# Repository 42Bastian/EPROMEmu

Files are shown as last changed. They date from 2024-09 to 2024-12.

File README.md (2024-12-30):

# LynxCartEmu

This repo is based on Brian's repo, see original comments below.

This fork is solely to support Atari Lynx Carts.
Upon start, the firmware loads either a `game.lnx` file or if not available provides a uBLL for Lynx.

A new ROM image can be uploaded (as .lnx file) and will be stored in internal RAM and on SD card (if available) for the next boot.

Sending is done via `SendCard.py`.

The firmware allows to "reload" the SD cart via serial command `cr` if game.lnx was saved on a PC on the card.

---

# EPROMEmu

**!! WARNING: I have no idea what I'm doing !!**

I've decided to make this public in the rare event it might help someone.

This is a very simple, likely very wrong (EP)ROM emulator using a Teensy 4.1 and Arduino/PlatformIO.  It works for my purposes (emulating an EPROM for
use in an Atari Lynx EPROM cartridge), but it it is probably not the "correct" way to design hardware.  I have also used it on Game Gear and Vectrex EPROM cartridges,
but it was not heavily tested.

Please take caution with using anything you see here.  It's my first time using KiCad, my first time designing a PCB, and my first time creating hardware.  Again,
it works for my purposes, but perhaps it'll burn your house down.

Enjoy!

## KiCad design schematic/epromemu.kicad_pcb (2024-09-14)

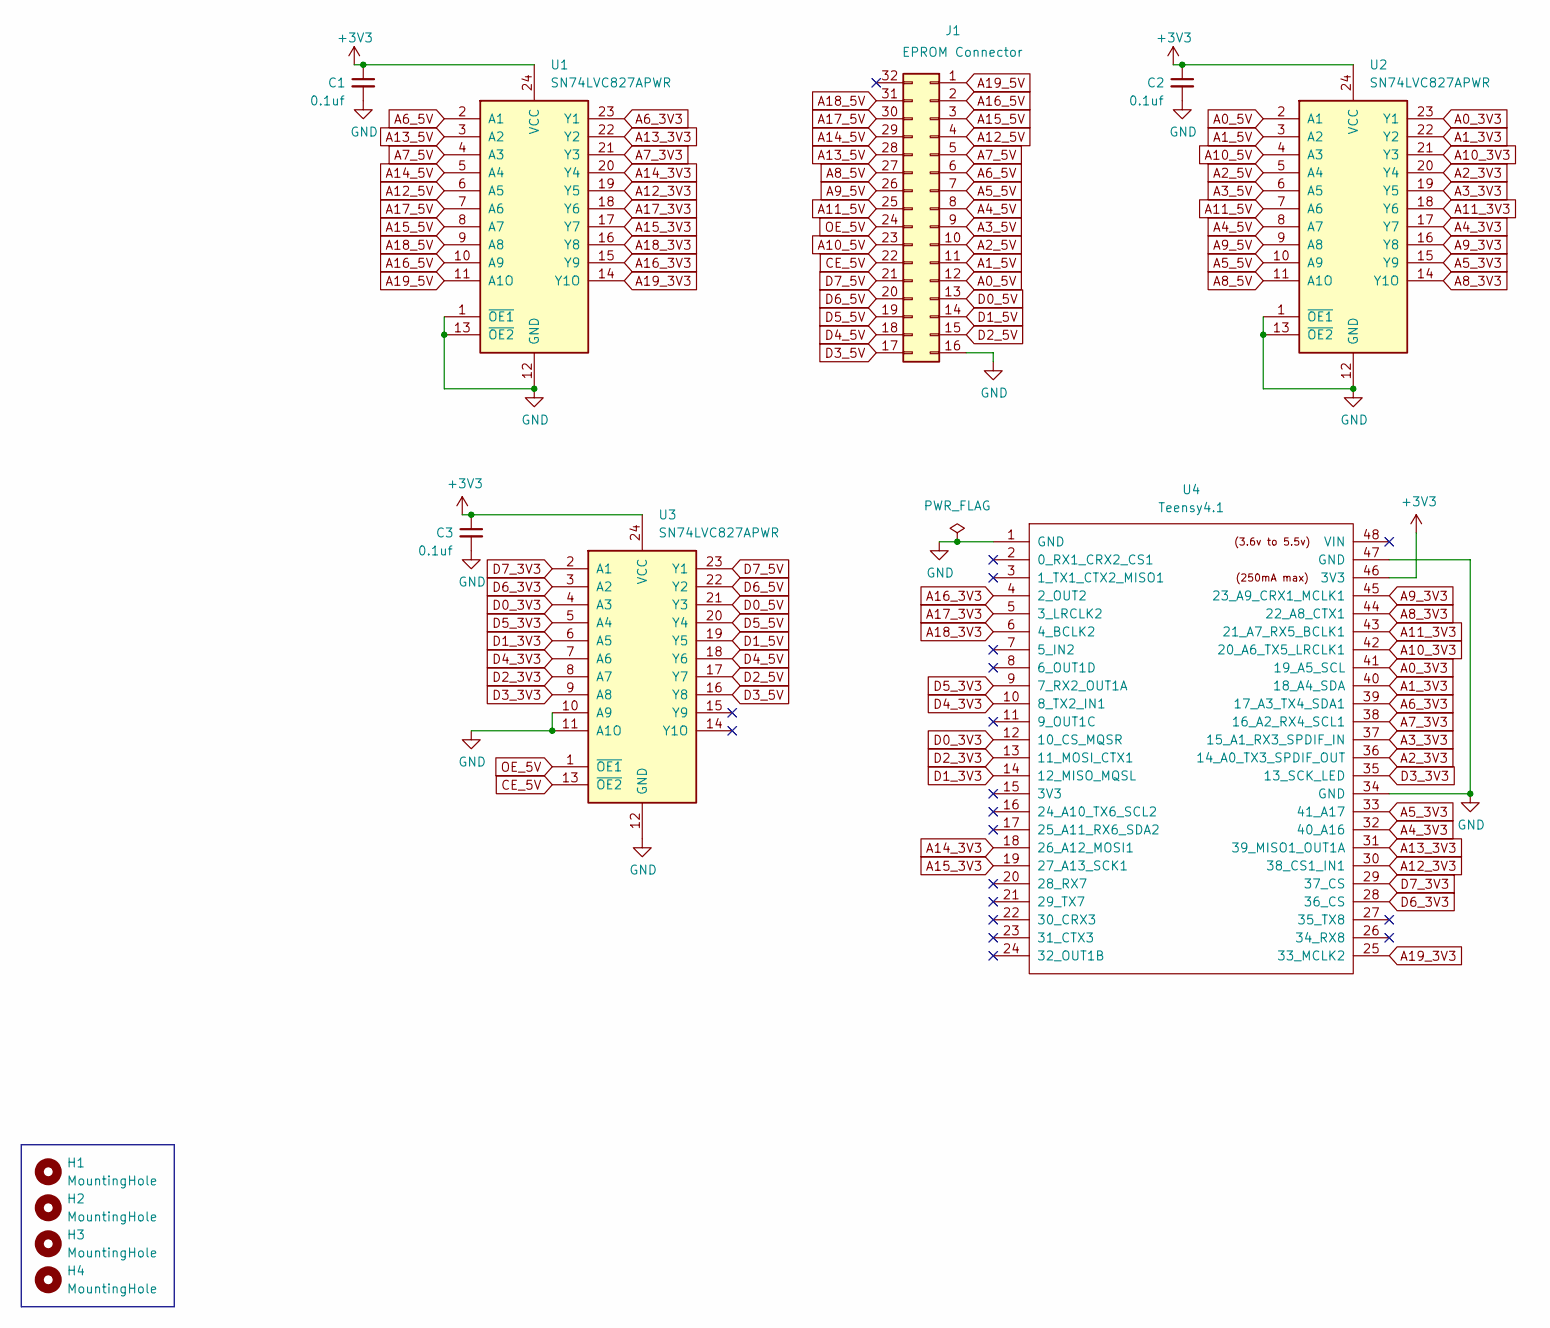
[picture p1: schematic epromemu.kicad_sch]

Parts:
C1, C2, C3: 0.1uf; C_0603_1608Metric_Pad1.08x0.95mm_HandSolder
H1, H2, H3, H4: MountingHole; MountingHole_2.2mm_M2_ISO7380
J1: EPROM Connector; PinHeader_2x16_P2.54mm_Vertical
U1, U2, U3: SN74LVC827APWR; SOIC-24W_7.5x15.4mm_P1.27mm
U4: Teensy4.1; Teensy41

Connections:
+3V3: C1.1, C2.1, C3.1, U1.24 (VCC), U2.24 (VCC), U3.24 (VCC), U4.46 (3V3)
A0_3V3: U2.23 (Y1), U4.41 (19_A5_SCL)
A0_5V: J1.12, U2.2 (A1)
A1_3V3: U2.22 (Y2), U4.40 (18_A4_SDA)
A1_5V: J1.11, U2.3 (A2)
A2_3V3: U2.20 (Y4), U4.36 (14_A0_TX3_SPDIF_OUT)
A2_5V: J1.10, U2.5 (A4)
A3_3V3: U2.19 (Y5), U4.37 (15_A1_RX3_SPDIF_IN)
A3_5V: J1.9, U2.6 (A5)
A4_3V3: U2.17 (Y7), U4.32 (40_A16)
A4_5V: J1.8, U2.8 (A7)
A5_3V3: U2.15 (Y9), U4.33 (41_A17)
A5_5V: J1.7, U2.10 (A9)
A6_3V3: U1.23 (Y1), U4.39 (17_A3_TX4_SDA1)
A6_5V: J1.6, U1.2 (A1)
A7_3V3: U1.21 (Y3), U4.38 (16_A2_RX4_SCL1)
A7_5V: J1.5, U1.4 (A3)
A8_3V3: U2.14 (Y1O), U4.44 (22_A8_CTX1)
A8_5V: J1.27, U2.11 (A1O)
A9_3V3: U2.16 (Y8), U4.45 (23_A9_CRX1_MCLK1)
A9_5V: J1.26, U2.9 (A8)
A10_3V3: U2.21 (Y3), U4.42 (20_A6_TX5_LRCLK1)
A10_5V: J1.23, U2.4 (A3)
A11_3V3: U2.18 (Y6), U4.43 (21_A7_RX5_BCLK1)
A11_5V: J1.25, U2.7 (A6)
A12_3V3: U1.19 (Y5), U4.30 (38_CS1_IN1)
A12_5V: J1.4, U1.6 (A5)
A13_3V3: U1.22 (Y2), U4.31 (39_MISO1_OUT1A)
A13_5V: J1.28, U1.3 (A2)
A14_3V3: U1.20 (Y4), U4.18 (26_A12_MOSI1)
A14_5V: J1.29, U1.5 (A4)
A15_3V3: U1.17 (Y7), U4.19 (27_A13_SCK1)
A15_5V: J1.3, U1.8 (A7)
A16_3V3: U1.15 (Y9), U4.4 (2_OUT2)
A16_5V: J1.2, U1.10 (A9)
A17_3V3: U1.18 (Y6), U4.5 (3_LRCLK2)
A17_5V: J1.30, U1.7 (A6)
A18_3V3: U1.16 (Y8), U4.6 (4_BCLK2)
A18_5V: J1.31, U1.9 (A8)
A19_3V3: U1.14 (Y1O), U4.25 (33_MCLK2)
A19_5V: J1.1, U1.11 (A1O)
CE_5V: J1.22, U3.13 (~OE2)
D0_3V3: U3.4 (A3), U4.12 (10_CS_MQSR)
D0_5V: J1.13, U3.21 (Y3)
D1_3V3: U3.6 (A5), U4.14 (12_MISO_MQSL)
D1_5V: J1.14, U3.19 (Y5)
D2_3V3: U3.8 (A7), U4.13 (11_MOSI_CTX1)
D2_5V: J1.15, U3.17 (Y7)
D3_3V3: U3.9 (A8), U4.35 (13_SCK_LED)
D3_5V: J1.17, U3.16 (Y8)
D4_3V3: U3.7 (A6), U4.10 (8_TX2_IN1)
D4_5V: J1.18, U3.18 (Y6)
D5_3V3: U3.5 (A4), U4.9 (7_RX2_OUT1A)
D5_5V: J1.19, U3.20 (Y4)
D6_3V3: U3.3 (A2), U4.28 (36_CS)
D6_5V: J1.20, U3.22 (Y2)
D7_3V3: U3.2 (A1), U4.29 (37_CS)
D7_5V: J1.21, U3.23 (Y1)
GND: C1.2, C2.2, C3.2, J1.16, U1.1 (~OE1), U1.12 (GND), U1.13 (~OE2), U2.1 (~OE1), U2.12 (GND), U2.13 (~OE2), U3.10 (A9), U3.11 (A1O), U3.12 (GND), U4.1 (GND), U4.34 (GND), U4.47 (GND)
OE_5V: J1.24, U3.1 (~OE1)

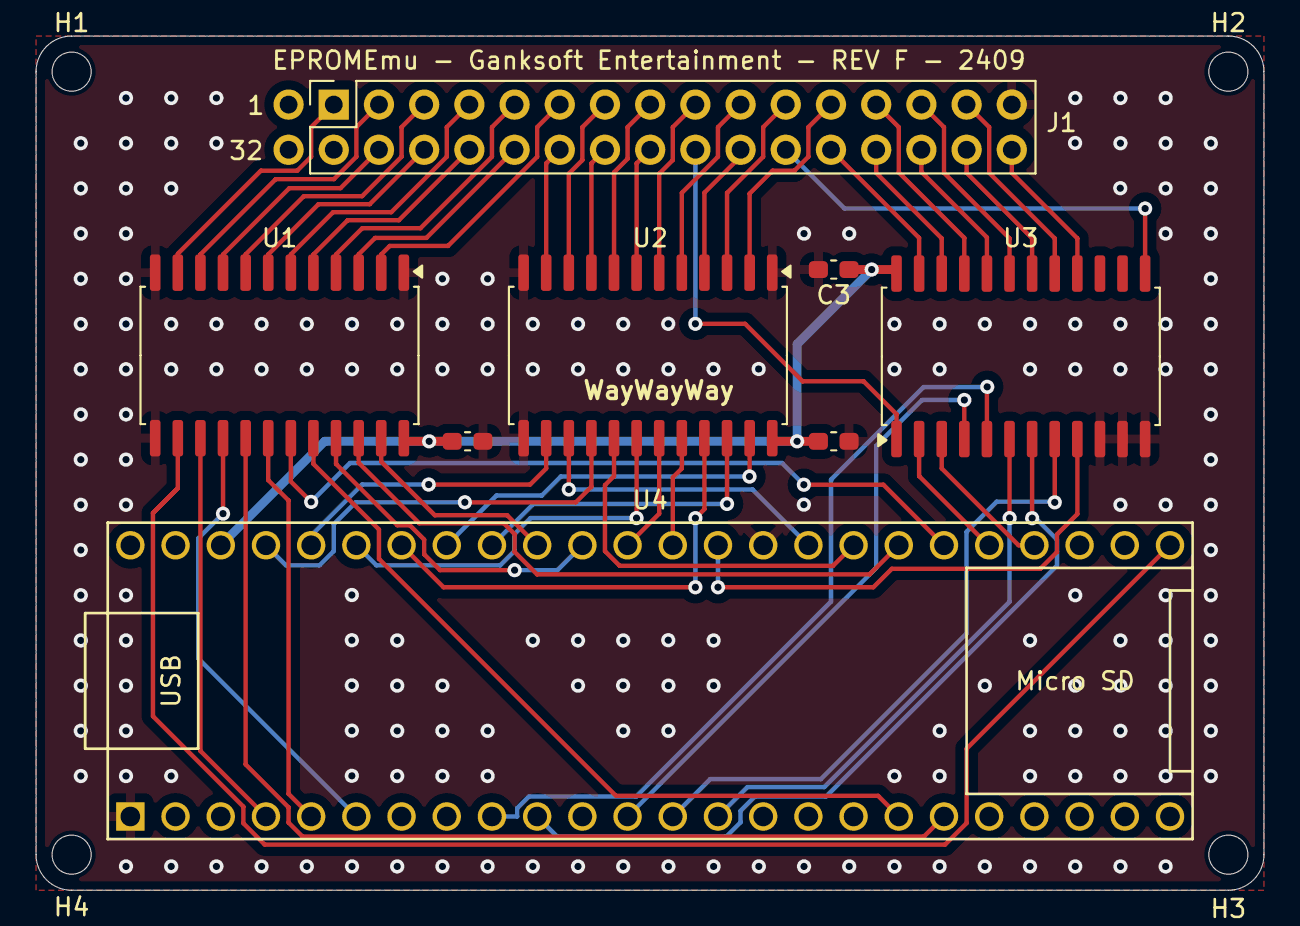
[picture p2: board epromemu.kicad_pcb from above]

Board: 2 copper layers, 69.0 x 48.0 mm, 13 parts (1 on the bottom side), 60 nets.

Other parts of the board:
GanksoftLogo: LOGO; GanksoftLogo

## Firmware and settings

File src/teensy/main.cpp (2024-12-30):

/*
** Teensy 4.1 firmware for LynxCartEmu
**
** (c) 2024 Brian Peek (original) and 42Bastian Schick (Lynx version)
**
*/
// FLASHMEM
// DMAMEM
// PROGMEM

#include <Arduino.h>
#include <SD.h>
#include <stdint.h>
#include "ubll.h"

enum cardSize : uint8_t {
  _128K = 1,
  _256K = 2,
  _512K = 3,
  _1M = 4,
};

typedef struct
{
  uint8_t  magic[4];
  uint16_t page_size_bank0;
  uint16_t page_size_bank1;
  uint16_t version;
  char     cartname[32];
  char     manufname[16];
  char     rotation;
  char     audBit;
  char     eeprom;
  char     spare[3];
} lnx_header_t;

constexpr size_t   ROM_BUFFER_LEN       = (256*1024);
constexpr uint32_t ROM_BUFFER_HI_MASK   = (ROM_BUFFER_LEN-1);
constexpr size_t   TOTAL_ROM_BUFFER_LEN = (2*ROM_BUFFER_LEN);

uint8_t bufferLo[ROM_BUFFER_LEN] {};
DMAMEM uint8_t bufferHi[ROM_BUFFER_LEN] {};

const int32_t inPins[]  = {
  19,18,14,15,40,41,17,16,22,23,20,21,38,39,26,27,2,3,4,33, -1
};
const int32_t outPins[] = {
  10,12,11,13,8,7,36,37, -1
};

constexpr const char *filenameLNX      = "game.lnx";
FS* g_fs = nullptr;
lnx_header_t lnx_header;
cardSize cSize = _256K;

int readLNX(Stream *s)
{
  size_t read;
  size_t total;
  uint8_t *buffer;
  size_t expected;

  memset(bufferLo, 0x42, sizeof(bufferLo));
  memset(bufferHi, 0x42, sizeof(bufferHi));
  memset(&lnx_header, 0xea, sizeof(lnx_header_t));

  read = s->readBytes((uint8_t *)&lnx_header, sizeof(lnx_header_t));

  expected = lnx_header.page_size_bank0 * 256;
  expected += lnx_header.page_size_bank1 * 256;

  total = 0;
  buffer = bufferLo;
  while( total < sizeof(bufferLo) && expected > 0 ){
    size_t wanted;

    wanted = sizeof(bufferLo) - total;
    wanted = wanted > 1024 ? 1024 : wanted;
    read = s->readBytes(buffer, wanted);
    if ( read <= 0 ) return 0;
    total += read;
    buffer += read;
    expected -= read;
  }
  total -= sizeof(bufferLo);

  buffer = bufferHi;
  while( total < sizeof(bufferHi) && expected > 0 ){
    size_t wanted;

    wanted = sizeof(bufferHi) - total;
    wanted = wanted > 1024 ? 1024 : wanted;
    read = s->readBytes(buffer, wanted);
    if ( read <= 0 ) return 0;
    total += read;
    buffer += read;
    expected -= read;
  }

  if( expected != 0 ) {
    return 0;
  }

  switch (lnx_header.page_size_bank0){
  case 512:
    cSize = _128K;
    break;
  case 1024:
    cSize = _256K;
    break;
  case 2048:
    cSize = _512K;
    break;
  default:
    cSize = _1M;
  }

  if ( g_fs->exists(filenameLNX)) {
    g_fs->remove(filenameLNX);
  }

  File f = g_fs->open(filenameLNX, FILE_WRITE);

  if ( f ){
    f.write((uint8_t *)&lnx_header, sizeof(lnx_header_t));

    expected = lnx_header.page_size_bank0 * 256;
    expected += lnx_header.page_size_bank1 * 256;

    f.write(bufferLo, min(sizeof(bufferLo),expected));
    f.write(bufferHi, expected-sizeof(bufferLo));
    f.close();
  }
  return 1;
}

void setPinMode(const int32_t* pins, uint32_t direction)
{
  for(int i = 0; pins[i] != -1; i++){
    pinMode(pins[i], direction);
  }
}

void checkSD()
{
  SD.begin(BUILTIN_SDCARD);
  g_fs = (FS*)&SD;

  if ( g_fs->exists(filenameLNX)) {
    Serial.printf("=> Found game.lnx:");

    File f = g_fs->open(filenameLNX, FILE_READ);
    int32_t sz = (int32_t)f.size();

    f.read(&lnx_header,64);
    Serial.printf("Size %ld\r\n",sz);
    Serial.flush();
    sz -= 64;
    f.read(bufferLo, min(sz,(int32_t)sizeof(bufferLo)));
    sz -= sizeof(bufferLo);
    if ( sz > 0 ){
      f.read(bufferHi,sz);
    }
    switch (lnx_header.page_size_bank0){
    case 512:
      cSize = _128K;
      break;
    case 1024:
      cSize = _256K;
      break;
    case 2048:
      cSize = _512K;
      break;
    default:
      cSize = _1M;
    }
    Serial.printf("Banksize: %d\r\n%s\r\n",cSize,lnx_header.cartname);
    f.close();
  } else {
    Serial.printf("No file found, switch to uBLL\r\n");
    memcpy(bufferLo, uBLL, sizeof(uBLL));
    strcpy(lnx_header.cartname, "uBLL");
    lnx_header.page_size_bank0 = 1024;
    lnx_header.page_size_bank1 = 0;
    cSize = _256K;
  }
}

void setup()
{
  Serial.begin(115200*8);

  checkSD();

  setPinMode(inPins, INPUT);
  setPinMode(outPins, OUTPUT);
  GPIO7_DR = 0;
}

void loop()
{
  uint32_t io6 = (GPIO6_DR >> 16);      //  A0 - A15
  uint32_t io9 = GPIO9_DR;              // A16 - A19
  uint32_t addr = 0;                    // calculated address

  switch(cSize) {
    // 1Mbit, 128KB, 0x00000-0x1FFFF
  case _128K:
    addr =    io6 & 0x001FF;         // Lynx A0  - A8  -> EPROM A0 - A8
    addr |=  (io6 >> 2)  & 0x03E00;  // Lynx A12 - A17 -> EPROM A11 - A15
    addr |= ((io9 << 10) & 0x1C000); // Lynx A18 - A19 -> EPROM A16
    break;

    // 2Mbit, 256KB, 0x00000-0x3FFFF
  case _256K:
    addr =    io6 & 0x003FF;         // Lynx A0  - A9  -> EPROM A0 - A9
    addr |=  (io6 >> 1)  & 0x07C00;  // Lynx A12 - A17 -> EPROM A11 - A15
    addr |= ((io9 << 11) & 0x38000); // Lynx A18 - A19 -> EPROM A16 - A17
    break;

    // 4Mbit, 512KB, 0x00000-0x7FFFF
  case _512K:
    // XXX: check for AUDIN
    addr =   io6;  // Lynx A0  - A10, A12-A17 -> EPROM A0 - A10, A11-A15
    addr |= ((io9 << 12) & 0x70000); // Lynx A18 - A19 -> EPROM A16 - A17
    break;

    // 8Mbit, 1MB, 0x00000-0xFFFFF
  case _1M:
    // XXX: check for AUDIN
    addr =   io6;  // Lynx A0  - A10, A12-A17 -> EPROM A0 - A10, A11-A15
    addr |= ((io9 << 12) & 0x70000); // Lynx A18 - A19 -> EPROM A16 - A17
    break;
  }

  uint8_t b;

  // get byte at addr
  if(addr < ROM_BUFFER_LEN){
    b = bufferLo[addr];
  } else {
    b = bufferHi[addr & ROM_BUFFER_HI_MASK];
  }

  // set data pins
  GPIO7_DR = (b & 0x0F) | ((b & 0xF0) << 12);

  // read file from serial port, if available
  if(Serial.available()){
    char command[2];
    command[0] = 0;
    Serial.readBytes(command,2);
    if ( command[0] == 'c' ){
      switch (command[1] ){
      case 'r':
        checkSD();
        break;
      case 'l':
        if ( !readLNX(&Serial) ){
          checkSD();
        }
        break;
      case 'i':
        Serial.printf("Name: %s\r\n"
                      "Page0: %d\r\n"
                      "Page1: %d\r\n"
                      ,lnx_header.cartname
                      ,lnx_header.page_size_bank0
                      ,lnx_header.page_size_bank1
                      );
        break;

      case 'h':
        {
//->          uint8_t *p = (uint8_t *)bufferLo;
//->          for(int i = 0; i < 64;++i){
//->            Serial.printf("%02x ",*p++);
//->          }
//->          Serial.printf("\n\r");
        }
        break;
      }
    }
  }
}

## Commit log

2024-08-14 v3 board, lynx support
2024-08-18 REV D
    [epromemu.kicad_pcb, epromemu.kicad_sch]
2024-09-14 REV E (unproduced)
    [epromemu.kicad_pcb, epromemu.kicad_sch]
2024-09-14 REV F
    [epromemu.kicad_pcb, epromemu.kicad_sch]
